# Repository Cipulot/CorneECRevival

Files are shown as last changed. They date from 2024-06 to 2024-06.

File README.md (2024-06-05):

# CorneECRevival

Revival project of the Corne ECWL.

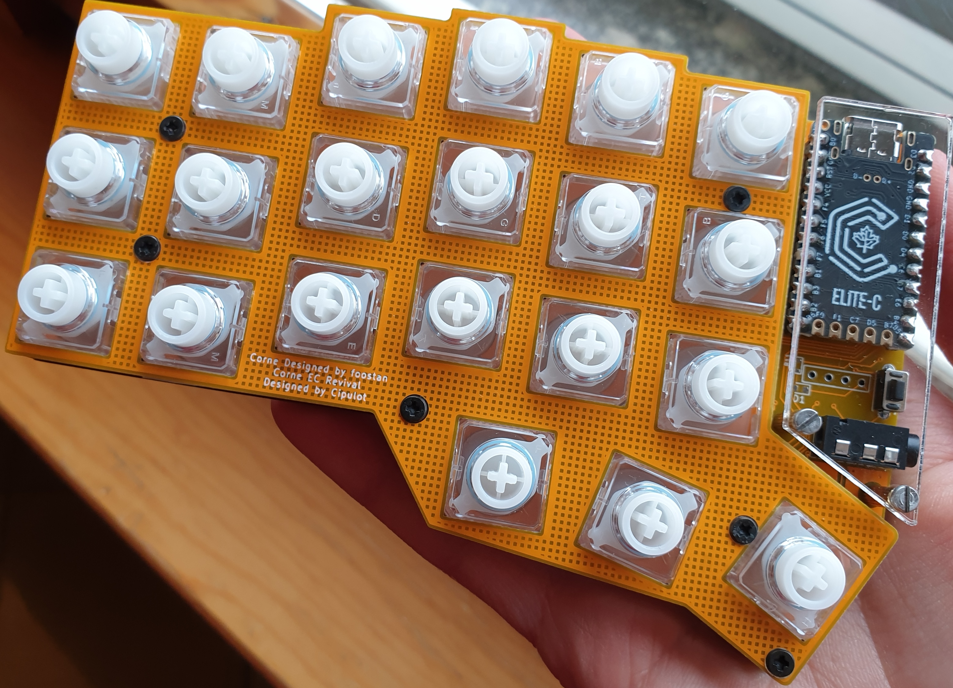
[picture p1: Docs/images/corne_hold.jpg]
Corneecrevival


Left half of Corne EC Revival Rev1.

## **DEPRECATED**

Please be advised that this project has been deprecated, and as of now, it is no longer supported. Regrettably, assistance or help cannot be provided for this deprecated project. The firmware is no longer targeting QMK main, and uses propositions that are now no lonfer working, making the project unusable.

The newer version, Corne EC, will have lots of new feature and will be run as a proper project that you can buy and enjoy right away.

## Introduction

The Corne EC Revival is my personal effort to revive the original Corne ECWL by [sekigon-gonnoc](https://github.com/sekigon-gonnoc).

It boosts full compatibility with the original boards sold by gonnoc while also providing updated QMK support for the latest stable release and a modified set of plates and pcbs, making it compatible with "standard" Corne accessories.

## PCB and Plate

Contrary to the standard Corne, the Corne EC Revival PCBs are not interchangable between left and right half. Plates on the other hand can be used on both sides.

In the [PCB folder](https://github.com/Cipulot/CorneECRevival/blob/main/PCB) there are all the PCB and plate design files. gerber files are in the [Production folder](https://github.com/Cipulot/CorneECRevival/blob/main/Production). The features of each revision are listed in the next section.

The naming scheme reflects the mounting system supported:

- `OG_mounting_[partname]` supports "standard" Corne mounting points
- `[partname]` supports the original Corne ECWL mounting points

Furthermore, to allow for a greater support, both NIZ and Topre housing plates are available for both mounting point configurations.

To see images and further description of the PCB refer to the dedicated section in the Notion build log [here](https://cipulot.notion.site/PCB-Design-9a60de99e9044c61900d82e630ff782b).

## Revisions

### Revision 1 (Rev1)

The Rev1 is the first iteration of the design, 1:1 compatible with the original Corne ECWL from Gonnoc.

The features are therefore shared with the original board with the extension of onboard Trackball and OLED.

Both ECWL mounting system and Standard Corne mounting points are supported with the respective PCB versions.

### Revision 2 (Rev2)

The Rev2 is a departure form the original design approach. It's a 'Ready to go!" board, meaning the MCU and complementary circuit is already onboard.

Added features compared from the Rev1 include:

- Onboard USB-C with ESD protection
- STM32F4x1 MCU for better performance, both cycle wise and in ADC performance compared to 32U4 (also 32U4 prices are to the moon as of now)
- APC (Actuation Point Changer) with predefined actuation points and full scale analog switch control (full board / per key)

Both NIZ and Topre are still supported.

## Production files

Gerber files are provided for all the pcbs of the project. BOM is also available to use. Placement files are WIP.

The prototypes were produced by JLC, therefore pretty much any PCB manufacturer can handle production without any problems.

## Firmware

The firmware folder contains 2 versions of the code based on different QMK releases:

- `EC Revival` based on the latest QMK stable
- `Original ECWL` based on gonnoc's fork, running on an older QMK branch

For the `EC Revival` there are going to be 2 configurations, one for the 32U4 (Rev1) and another for STM32F4x1 (Rev2).

Both have precompiled `*.hex` files based on the code in their respective folders to easily get the board up and running.

## License

<br />This work is licensed under a <a rel="license" href="http://creativecommons.org/licenses/by-nc-sa/4.0/">Creative Commons Attribution-NonCommercial-ShareAlike 4.0 International License</a>.

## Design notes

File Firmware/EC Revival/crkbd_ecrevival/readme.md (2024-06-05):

# Corne EC Revival

corne_ec_revival

*Revival project of the Corne ECWL*

* Keyboard Maintainer: [Cipulot](https://github.com/yourusername)
* Hardware Supported: PCB files [here](https://github.com/Cipulot/CorneECRevival/tree/main/PCB).
* Hardware Availability: TBD

Make example for this keyboard (after setting up your build environment):

    make crkbd_ecrevival:left_default
    make crkbd_ecrevival:right_default

Flashing example for this keyboard:

    make crkbd_ecrevival:left_default:flash
    make crkbd_ecrevival:right_default:flash

See the [build environment setup](https://docs.qmk.fm/#/getting_started_build_tools) and the [make instructions](https://docs.qmk.fm/#/getting_started_make_guide) for more information. Brand new to QMK? Start with our [Complete Newbs Guide](https://docs.qmk.fm/#/newbs).

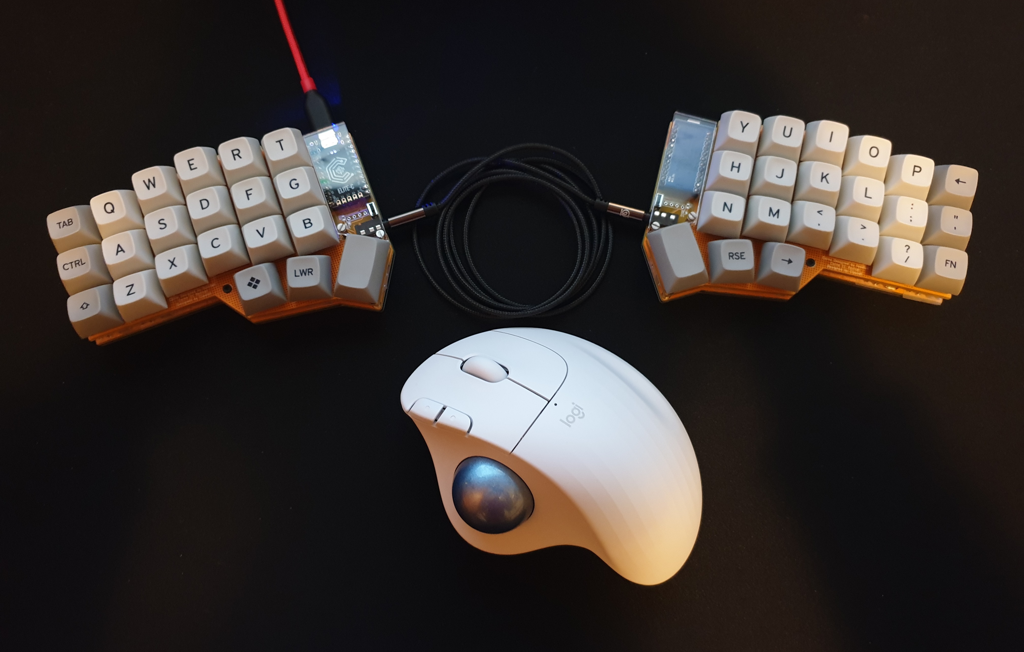
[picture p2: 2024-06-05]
Docs/images/Preview.jpg

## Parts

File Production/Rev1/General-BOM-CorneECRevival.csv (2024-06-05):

Comment | Designator | Footprint | NOTE: BOM for a single half. R10 standard value is 22k but can be changed to modify the OpAmp gain
LED | D1 | D_0603_1608Metric
R | R11 | R_0603
SW_Push | SW1 | SW_3.5x6.0_TH
MJ-4PP-9 | J2 | TRRS-PJ-320A-no-Fmask
100k | R2 | R_0603_1608Metric_Pad0.98x0.95mm_HandSolder
100k | R1 | R_0603_1608Metric_Pad0.98x0.95mm_HandSolder
100k | R3 | R_0603_1608Metric_Pad0.98x0.95mm_HandSolder
100k | R6 | R_0603_1608Metric_Pad0.98x0.95mm_HandSolder
74HC4051 | U1 | TSSOP16
22k | R10 | R_0603_1608Metric_Pad0.98x0.95mm_HandSolder
LTC6255 | U2 | TSOT-23-6_HandSoldering
100k | R5 | R_0603_1608Metric_Pad0.98x0.95mm_HandSolder
100k | R8 | R_0603_1608Metric_Pad0.98x0.95mm_HandSolder
1k | R9 | R_0603_1608Metric_Pad0.98x0.95mm_HandSolder
0.1u | C1 | C_0603_1608Metric_Pad1.08x0.95mm_HandSolder
Q_NMOS_GSD | Q1 | SOT-23
0.1u | C2 | C_0603_1608Metric_Pad1.08x0.95mm_HandSolder
100k | R4 | R_0603_1608Metric_Pad0.98x0.95mm_HandSolder
220p | C3 | C_0603_1608Metric_Pad1.08x0.95mm_HandSolder
100k | R7 | R_0603_1608Metric_Pad0.98x0.95mm_HandSolder

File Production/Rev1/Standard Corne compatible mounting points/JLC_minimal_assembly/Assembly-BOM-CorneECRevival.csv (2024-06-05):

Comment | Designator | Footprint | LCSC
100k | R1, R2, R3, R4, R5, R6, R7, R10 | R_0603_1608Metric_Pad0.98x0.95mm_HandSolder | C25803
1k | R9 | R_0603_1608Metric_Pad0.98x0.95mm_HandSolder | C21190
0.1u | C1, C2 | C_0603_1608Metric_Pad1.08x0.95mm_HandSolder | C14663
220p | C3 | C_0603_1608Metric_Pad1.08x0.95mm_HandSolder | C302060
74HC4051 | U1 | TSSOP16 | C5645
LTC6255 | U2 | TSOT-23-6_HandSoldering | C117251

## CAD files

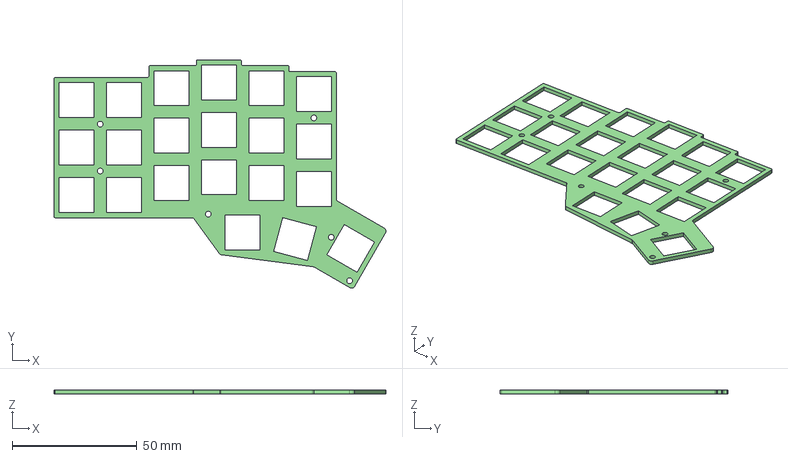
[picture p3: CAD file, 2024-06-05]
Assets/3dmodels/Rev1/ECWL compatible mounting points/plate.step
132.9 x 91.4 x 1.60 mm

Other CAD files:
Assets/3dmodels/Rev1/Standard Corne compatible mounting points/OG_mounting_plate_Topre.step
Assets/3dmodels/Rev1/ECWL compatible mounting points/plate_Topre.step
Assets/3dmodels/Rev1/Standard Corne compatible mounting points/OG_mounting_plate.step

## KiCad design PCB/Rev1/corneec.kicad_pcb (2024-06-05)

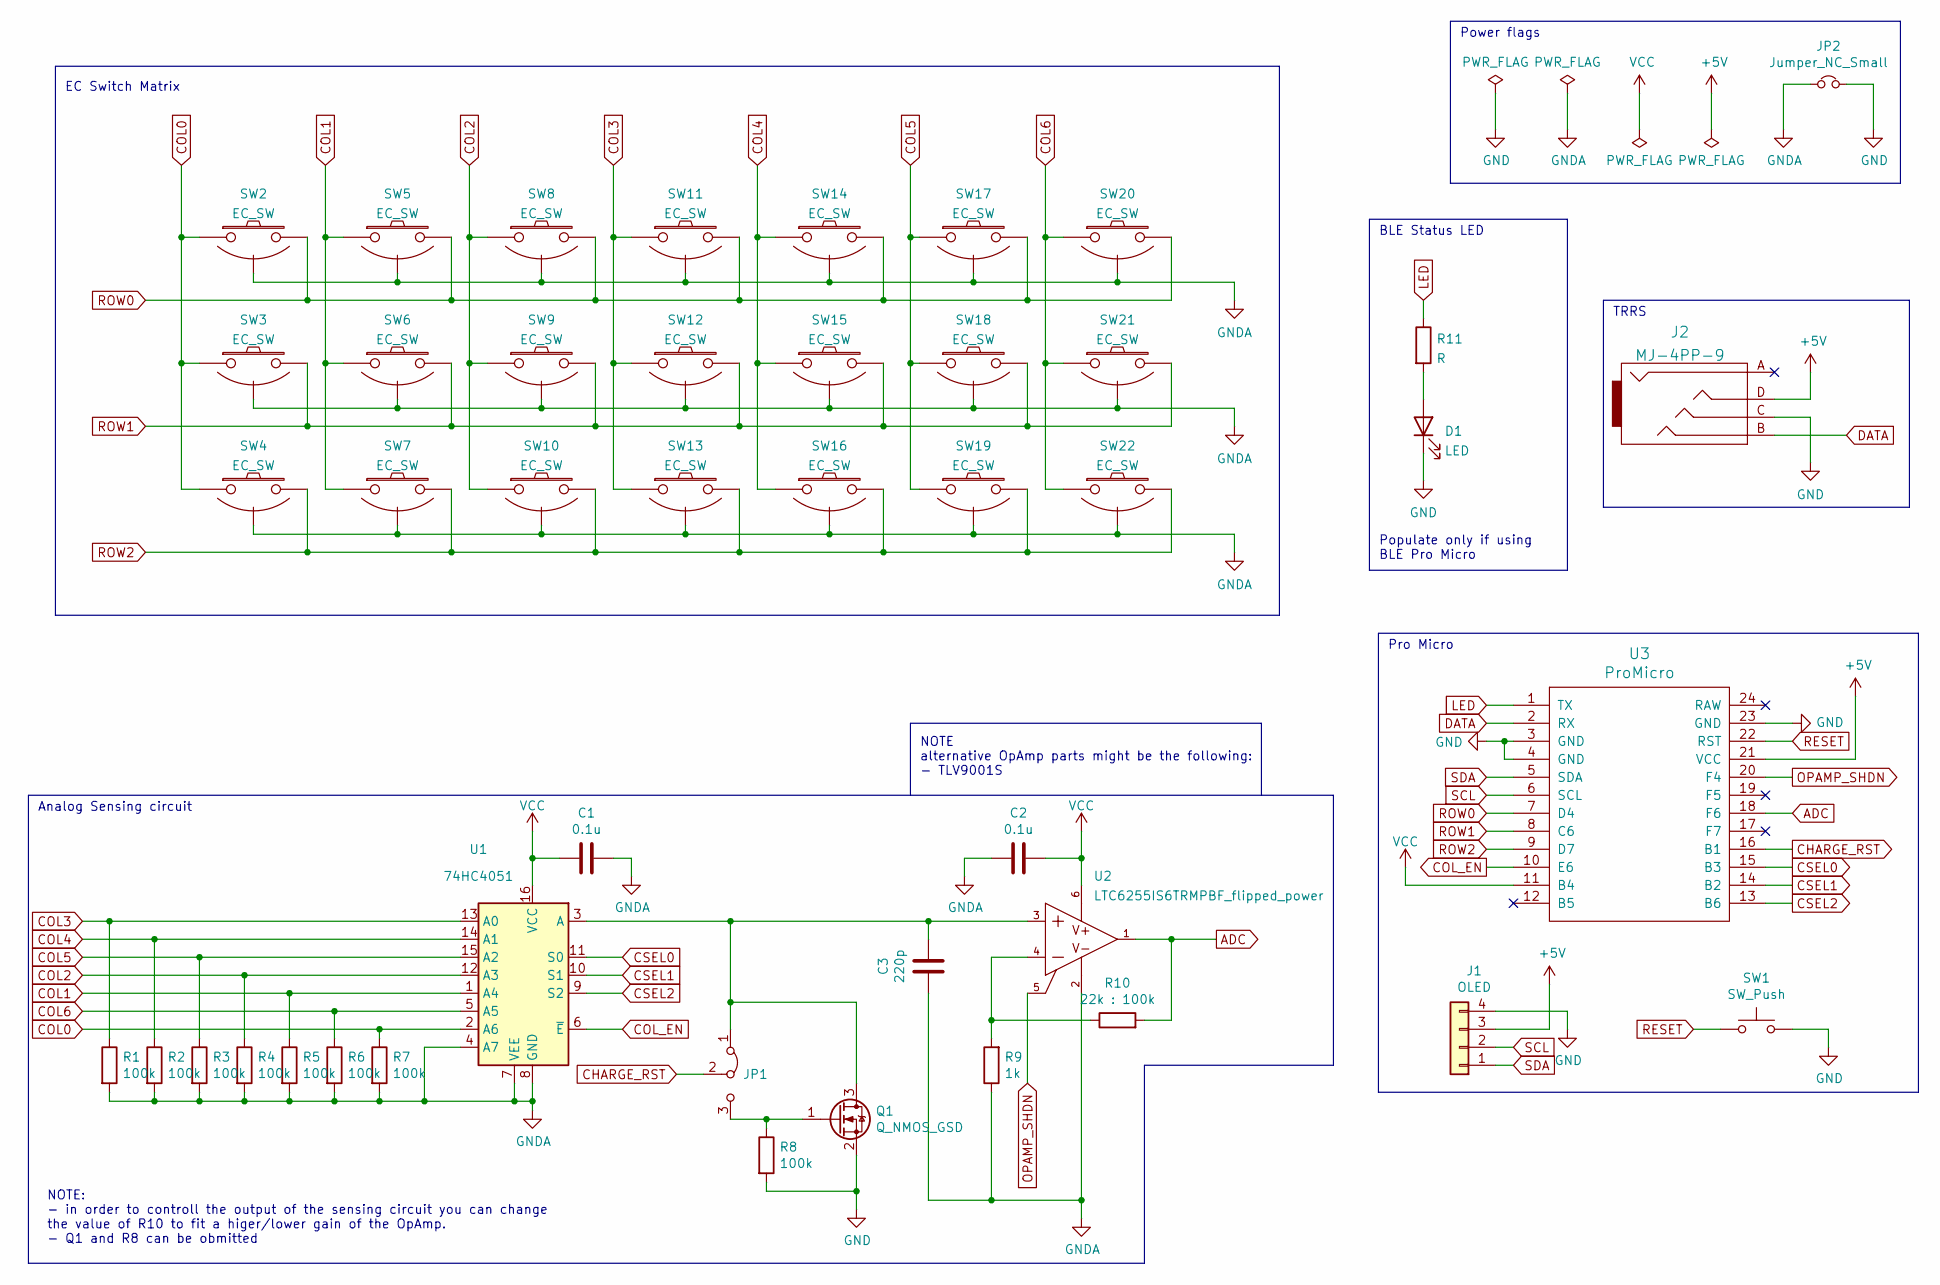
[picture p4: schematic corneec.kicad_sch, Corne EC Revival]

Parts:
C1, C2: 0.1u; C_0603_1608Metric_Pad1.08x0.95mm_HandSolder
C3: 220p; C_0603_1608Metric_Pad1.08x0.95mm_HandSolder
D1: LED; D_0603_1608Metric
J1: OLED; OLED_Small
J2: MJ-4PP-9; TRRS-PJ-320A-no-Fmask
JP1: Jumper_3_Bridged12; SolderJumper-3_P1.3mm_Bridged12_Pad1.0x1.5mm
JP2: Jumper_NC_Small; SolderJumper-2_P1.3mm_Bridged_Pad1.0x1.5mm
Q1: Q_NMOS_GSD; SOT-23
R1, R2, R3, R4, R5, R6, R7, R8: 100k; R_0603_1608Metric_Pad0.98x0.95mm_HandSolder
R9: 1k; R_0603_1608Metric_Pad0.98x0.95mm_HandSolder
R10: 22k : 100k; R_0603_1608Metric_Pad0.98x0.95mm_HandSolder
R11: R; R_0603
SW1: SW_Push; SW_3.5x6.0_TH
SW2, SW3, SW4, SW5, SW6, SW7, SW8, SW9, SW10, SW11, SW12, SW13, SW14, SW15, SW16, SW17, SW18, SW19, SW20, SW21, SW22: EC_SW; ecs_pad
U1: 74HC4051; TSSOP16
U2: LTC6255IS6TRMPBF_flipped_power; TSOT-23-6_HandSoldering
U3: ProMicro; Sparkfun_Pro_Micro

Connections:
+5V: J1.3, J2.D, U3.21 (VCC)
ADC: R10.2, U2.1 (OUT), U3.18 (F6)
CHARGE_RST: JP1.2 (C), U3.16 (B1)
COL0: R7.1, SW2.1, SW3.1, SW4.1, U1.2 (A6)
COL1: R5.1, SW5.1, SW6.1, SW7.1, U1.1 (A4)
COL2: R4.1, SW8.1, SW9.1, SW10.1, U1.12 (A3)
COL3: R1.1, SW11.1, SW12.1, SW13.1, U1.13 (A0)
COL4: R2.1, SW14.1, SW15.1, SW16.1, U1.14 (A1)
COL5: R3.1, SW17.1, SW18.1, SW19.1, U1.15 (A2)
COL6: R6.1, SW20.1, SW21.1, SW22.1, U1.5 (A5)
COL_EN: U1.6 (~E), U3.10 (E6)
CSEL0: U1.11 (S0), U3.15 (B3)
CSEL1: U1.10 (S1), U3.14 (B2)
CSEL2: U1.9 (S2), U3.13 (B6)
DATA: J2.B, U3.2 (RX)
GND: D1.1 (K), J1.4, J2.C, JP2.2, Q1.2 (S), R8.2, SW1.2, U3.3 (GND), U3.4 (GND), U3.23 (GND)
GNDA: C1.1, C2.2, C3.2, JP2.1, R1.2, R2.2, R3.2, R4.2, R5.2, R6.2, R7.2, R9.1, SW2.3 (SG), SW3.3 (SG), SW4.3 (SG), SW5.3 (SG), SW6.3 (SG), SW7.3 (SG), SW8.3 (SG), SW9.3 (SG), SW10.3 (SG), SW11.3 (SG), SW12.3 (SG), SW13.3 (SG), SW14.3 (SG), SW15.3 (SG), SW16.3 (SG), SW17.3 (SG), SW18.3 (SG), SW19.3 (SG), SW20.3 (SG), SW21.3 (SG), SW22.3 (SG), U1.4 (A7), U1.7 (VEE), U1.8 (GND), U2.2 (V-)
LED: R11.1, U3.1 (TX)
unnamed: C3.1, JP1.1 (A), Q1.3 (D), U1.3 (A), U2.3 (+IN)
unnamed: D1.2 (A), R11.2
unnamed: JP1.3 (B), Q1.1 (G), R8.1
unnamed: R9.2, R10.1, U2.4 (-IN)
OPAMP_SHDN: U2.5 (~SHDN), U3.20 (F4)
RESET: SW1.1, U3.22 (RST)
ROW0: SW2.2, SW5.2, SW8.2, SW11.2, SW14.2, SW17.2, SW20.2, U3.7 (D4)
ROW1: SW3.2, SW6.2, SW9.2, SW12.2, SW15.2, SW18.2, SW21.2, U3.8 (C6)
ROW2: SW4.2, SW7.2, SW10.2, SW13.2, SW16.2, SW19.2, SW22.2, U3.9 (D7)
SCL: J1.2, U3.6 (SCL)
SDA: J1.1, U3.5 (SDA)
VCC: C1.2, C2.1, U1.16 (VCC), U2.6 (V+), U3.11 (B4)

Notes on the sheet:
TRRS
NOTE alternative OpAmp parts might be the following: - TLV9001S
Populate only if using BLE Pro Micro
Pro Micro
NOTE: - in order to controll the output of the sensing circuit you can change the value of R10 to fit a higer/lower gain of the OpAmp. - Q1 and R8 can be obmitted
EC Switch Matrix
Analog Sensing circuit
BLE Status LED
Power flags

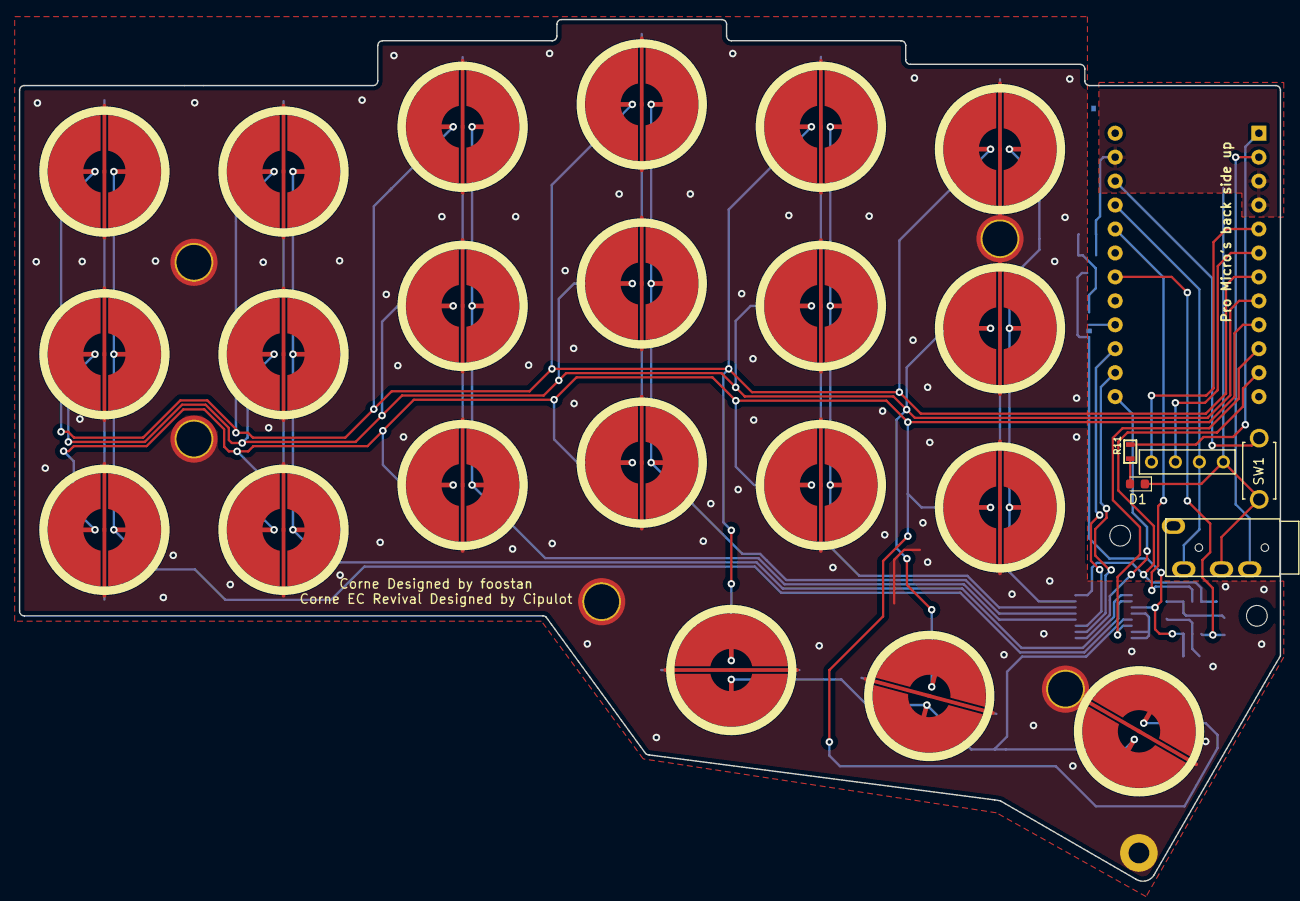
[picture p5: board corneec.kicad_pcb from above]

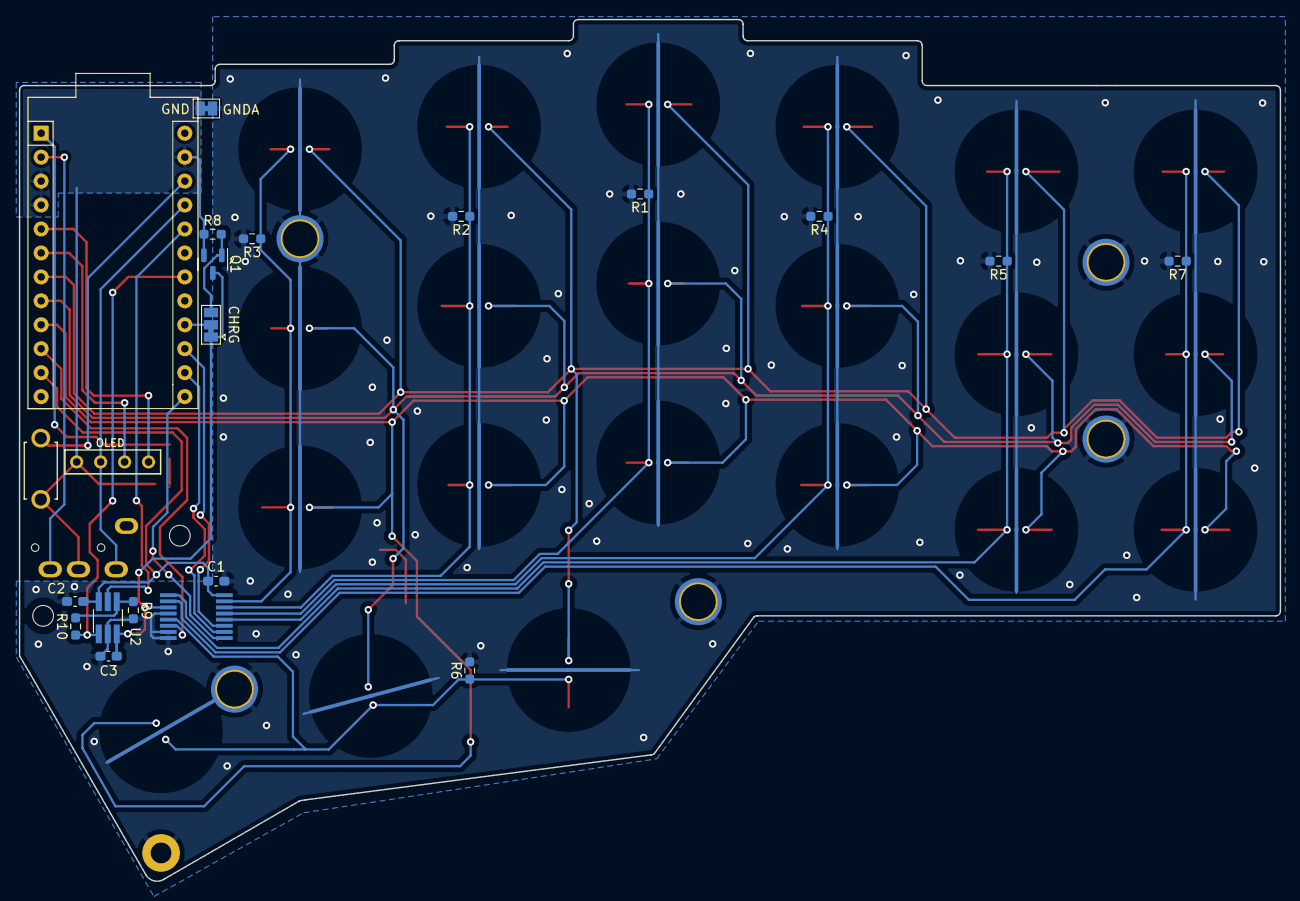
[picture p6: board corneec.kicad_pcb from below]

Board: 2 copper layers, 133.8 x 91.4 mm, 46 parts (19 on the bottom side), 30 nets.

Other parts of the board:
H22: MountingHole; HOLE_M2

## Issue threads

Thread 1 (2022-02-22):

not found footprint for library

whitenight209, 2022-02-22:
i like to refer this proejct.
but i cant found footprint of library such as ec switch.
please consider contain footprint for libraries.

whitenight209, 2022-02-22:
thanks.😀

Closed 2022-02-22.

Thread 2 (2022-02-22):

Build guide

brneor, 2022-02-22:
Sorry for bothering you with this but are you willing to provide a build guide?

Thank you very much for your work on this board, really apreciate it :)

Cipulot, 2022-02-22:
Hi there 👋
I'm in the process of creating a build guide rn, with a dedicated section at the end about the calibration process too.
It will be available here and on the dedicated Notion page linked in the home of the repo. Here's a quick [link](https://cipulot.notion.site/Corne-EC-Revival-203d1983000b400290df213aa76ce73b) for reference. I think that by the end of the week I'll have it finished.

brneor, 2022-02-22:
Thank you so much! I've already read your Notion pages and although I'm a electronic illiterate I appreciate your effort in creating such detailed documentation :)

Cipulot, 2022-02-22:
Hi there @brneor 👋 ,
I've added the build guide to the [Notion page](https://cipulot.notion.site/Corne-EC-Revival-203d1983000b400290df213aa76ce73b), detailing the PCB building and parts, as well as the mechanical assembly(standoffs, screws and case).

Closed 2022-02-22.

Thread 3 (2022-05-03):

PCB for Rev2

joric, 2022-05-03:
Where are the Rev2 boards? There are only plates in the Rev2 directory.

Cipulot, 2022-05-03:
Rev2 is still in the work. Additional pcb and plates will be added once I finish design and testing of protos.

Closed 2022-05-03.

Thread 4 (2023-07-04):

what is the manufacturer and specific model of Q_NMOS_GSD？

zhushenzhi, 2023-07-04:
Hello, I'm replicating a keyboard and having trouble sourcing the right Q_NMOS_GSD component. The JLC recommendations seem incorrect due to package model inconsistencies. Could you advise on the correct manufacturer, model, voltage, and current for Q_NMOS_GSD?

Cipulot, 2023-07-04:
`Q1` and `R8` can be left unpopulated.

Closed 2023-07-04.

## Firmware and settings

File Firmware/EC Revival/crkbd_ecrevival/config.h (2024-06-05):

/*
Copyright 2022 Cipulot

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
You should have received a copy of the GNU General Public License
along with this program.  If not, see <http://www.gnu.org/licenses/>.
*/

#pragma once

#include "config_common.h"

/* USB Device descriptor parameter */
#define VENDOR_ID    0xFEED
#define PRODUCT_ID   0x6B71
#define DEVICE_VER   0x0001
#define MANUFACTURER    Cipulot
#define PRODUCT         Corne EC Revival
#define DESCRIPTION     A split capacitive/true-wireless keyboard

/* key matrix size */
#define MATRIX_ROWS 6
#define MATRIX_COLS 7

/*
 * Keyboard Matrix Assignments
 *
 * Change this to how you wired your keyboard
 * COLS: AVR pins used for columns, left to right
 * ROWS: AVR pins used for rows, top to bottom
 * DIODE_DIRECTION: COL2ROW = COL = Anode (+), ROW = Cathode (-, marked on diode)
 *                  ROW2COL = ROW = Anode (+), COL = Cathode (-, marked on diode)
 *
 */
#define POWER_PIN B4
#define APLEX_EN_PIN E6
#define OPA_SHDN_PIN F4
#define DISCHARGE_PIN B1
#define ANALOG_PORT F6

#define MATRIX_ROW_PINS { D4, C6, D7 }
#define MATRIX_COL_CHANNELS { 6, 4, 3, 0, 1, 2, 5 }
#define MUX_SEL_PINS { B3, B2, B6 }

#define UNUSED_PINS
/*
#define MATRIX_ROW_PINS { 0 } // Use custom matrix.c
#define MATRIX_COL_PINS { 0 } // Use custom matrix.c
#define UNUSED_PINS
*/

/* COL2ROW, ROW2COL */
#define DIODE_DIRECTION COL2ROW

/*
 * Split Keyboard specific options, make sure you have 'SPLIT_KEYBOARD = yes' in your rules.mk, and define SOFT_SERIAL_PIN.
 */

#define USE_SERIAL
#define SOFT_SERIAL_PIN D2  // or D1, D2, D3, E6
#define MASTER_LEFT


/* Debounce reduces chatter (unintended double-presses) - set 0 if debouncing is not needed */
#define DEBOUNCE 5

/* Mechanical locking support. Use KC_LCAP, KC_LNUM or KC_LSCR instead in keymap */
#define LOCKING_SUPPORT_ENABLE
/* Locking resynchronize hack */
#define LOCKING_RESYNC_ENABLE

/* disable these deprecated features by default */
#define NO_ACTION_MACRO
#define NO_ACTION_FUNCTION

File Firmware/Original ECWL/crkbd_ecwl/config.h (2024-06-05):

/*
Copyright 2020 sekigon-gonnoc

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
You should have received a copy of the GNU General Public License
along with this program.  If not, see <http://www.gnu.org/licenses/>.
*/

#pragma once

#include "config_common.h"

/* USB Device descriptor parameter */
#define VENDOR_ID    0xFEED
#define PRODUCT_ID   0x3060
#define DEVICE_VER   0x0001
#define MANUFACTURER    sekigon-gonnoc
#define PRODUCT         Corne ECWL
#define DESCRIPTION     A split capacitive/true-wireless keyboard

/* key matrix size */
#define MATRIX_ROWS 6
#define MATRIX_COLS 7

/*
 * Keyboard Matrix Assignments
 *
 * Change this to how you wired your keyboard
 * COLS: AVR pins used for columns, left to right
 * ROWS: AVR pins used for rows, top to bottom
 * DIODE_DIRECTION: COL2ROW = COL = Anode (+), ROW = Cathode (-, marked on diode)
 *                  ROW2COL = ROW = Anode (+), COL = Cathode (-, marked on diode)
 *
 */
#define MATRIX_ROW_PINS { 0 } // Use custom matrix.c
#define MATRIX_COL_PINS { 0 } // Use custom matrix.c
#define UNUSED_PINS

/* COL2ROW, ROW2COL */
#define DIODE_DIRECTION COL2ROW

/*
 * Split Keyboard specific options, make sure you have 'SPLIT_KEYBOARD = yes' in your rules.mk, and define SOFT_SERIAL_PIN.
 */
#define SOFT_SERIAL_PIN D2  // or D1, D2, D3, E6
#define EE_HANDS

//#define BACKLIGHT_PIN B7
//#define BACKLIGHT_LEVELS 3
//#define BACKLIGHT_BREATHING

//#define RGB_DI_PIN E2
//#ifdef RGB_DI_PIN
//#    define RGBLED_NUM 16
//#    define RGBLIGHT_HUE_STEP 8
//#    define RGBLIGHT_SAT_STEP 8
//#    define RGBLIGHT_VAL_STEP 8
//#    define RGBLIGHT_LIMIT_VAL 255 /* The maximum brightness level */
//#    define RGBLIGHT_SLEEP  /* If defined, the RGB lighting will be switched off when the host goes to sleep */
/*== all animations enable ==*/
//#    define RGBLIGHT_ANIMATIONS
/*== or choose animations ==*/
//#    define RGBLIGHT_EFFECT_BREATHING
//#    define RGBLIGHT_EFFECT_RAINBOW_MOOD
//#    define RGBLIGHT_EFFECT_RAINBOW_SWIRL
//#    define RGBLIGHT_EFFECT_SNAKE
//#    define RGBLIGHT_EFFECT_KNIGHT
//#    define RGBLIGHT_EFFECT_CHRISTMAS
//#    define RGBLIGHT_EFFECT_STATIC_GRADIENT
//#    define RGBLIGHT_EFFECT_RGB_TEST
//#    define RGBLIGHT_EFFECT_ALTERNATING
/*== customize breathing effect ==*/
/*==== (DEFAULT) use fixed table instead of exp() and sin() ====*/
//#    define RGBLIGHT_BREATHE_TABLE_SIZE 256      // 256(default) or 128 or 64
/*==== use exp() and sin() ====*/
//#    define RGBLIGHT_EFFECT_BREATHE_CENTER 1.85  // 1 to 2.7
//#    define RGBLIGHT_EFFECT_BREATHE_MAX    255   // 0 to 255
//#endif

/* Debounce reduces chatter (unintended double-presses) - set 0 if debouncing is not needed */
#define DEBOUNCE 5

/* define if matrix has ghost (lacks anti-ghosting diodes) */
//#define MATRIX_HAS_GHOST

/* Mechanical locking support. Use KC_LCAP, KC_LNUM or KC_LSCR instead in keymap */
#define LOCKING_SUPPORT_ENABLE
/* Locking resynchronize hack */
#define LOCKING_RESYNC_ENABLE

/* If defined, GRAVE_ESC will always act as ESC when CTRL is held.
 * This is useful for the Windows task manager shortcut (ctrl+shift+esc).
 */
//#define GRAVE_ESC_CTRL_OVERRIDE

/*
 * Force NKRO
 *
 * Force NKRO (nKey Rollover) to be enabled by default, regardless of the saved
 * state in the bootmagic EEPROM settings. (Note that NKRO must be enabled in the
 * makefile for this to work.)
 *
 * If forced on, NKRO can be disabled via magic key (default = LShift+RShift+N)
 * until the next keyboard reset.
 *
 * NKRO may prevent your keystrokes from being detected in the BIOS, but it is
 * fully operational during normal computer usage.
 *
 * For a less heavy-handed approach, enable NKRO via magic key (LShift+RShift+N)
 * or via bootmagic (hold SPACE+N while plugging in the keyboard). Once set by
 * bootmagic, NKRO mode will always be enabled until it is toggled again during a
 * power-up.
 *
 */
//#define FORCE_NKRO

/*
 * Feature disable options
 *  These options are also useful to firmware size reduction.
 */

/* disable debug print */
//#define NO_DEBUG

/* disable print */
//#define NO_PRINT

/* disable action features */
//#define NO_ACTION_LAYER
//#define NO_ACTION_TAPPING
//#define NO_ACTION_ONESHOT

/* disable these deprecated features by default */
#define NO_ACTION_MACRO
#define NO_ACTION_FUNCTION

/* Bootmagic Lite key configuration */
//#define BOOTMAGIC_LITE_ROW 0
//#define BOOTMAGIC_LITE_COLUMN 0

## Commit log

2024-03-03 Update
    Updated the License for the project and relative details.
    [OG_mounting_left.kicad_pcb, OG_mounting_plate.kicad_pcb, OG_mounting_plate_Topre.kicad_pcb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]
2024-06-05 CorneECRevival cleanup
    [Assembly-BOM-CorneECRevival.csv, General-BOM-CorneECRevival.csv, OG_mounting_left.kicad_pcb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]

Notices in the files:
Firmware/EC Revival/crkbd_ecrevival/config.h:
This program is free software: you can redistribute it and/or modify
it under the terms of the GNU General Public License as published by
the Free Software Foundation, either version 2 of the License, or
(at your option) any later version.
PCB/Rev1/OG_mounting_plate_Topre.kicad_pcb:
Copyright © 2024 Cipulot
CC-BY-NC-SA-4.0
